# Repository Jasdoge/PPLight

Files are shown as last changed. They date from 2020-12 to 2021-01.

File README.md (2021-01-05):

# Usage:

1. The lamp automatically turns on when you move it
2. The lamp starts fading out after being still for 30 seconds, fully turning off after another 30 seconds.

## Charging:

1. Plug it to a 5V USB outlet with a Type-C cable.
2. The battery only charges at 100mA, so even a computer port will be able to charge it.
3. While charging, the lights will fade in and out with a pause between.
4. When fully charged, the lights will turn off.
5. A fully discharged battery reaches 90%+ charge in 2 hours.

## Troubleshooting:

1. After charging, you may need to led the device be still for a few seconds before it can turn on again.
2. If the device still won't turn on, you may need to reset it (this should be exceedingly rare though, and I didn't manage to reproduce it myself after setting the proper BOD). To reset it, open the case by removing the lid (but be careful since the silk filament is a little brittle), and use a fork or knife to briefly short the BAT1 solder joints.

# 3d printing

The 3d print files are located in the Prints director. It's designed for a multi material printer where you want to combine the lid and logo into one mesh, giving the logo priority.

# Schematics

Schematics are located within the Kicad directory.

# Reprogramming

If you want to reprogram your light you'll need the following:

- An arduino (pref arduino UNO)
- A breadboard
- A 10uF electrolytic capacitor
- A 4.7 kOhm resistor.
- 8-pin SOIC test clips. https://www.aliexpress.com/item/33058340727.html

1. Install the MegaTinyCore library in arduino. (If you haven't installed Arduino, do so at https://www.arduino.cc/
2. Then follow the instructions here: https://github.com/SpenceKonde/megaTinyCore/blob/master/MakeUPDIProgrammer.md But **do not connect the power pin to the PPLight**. In the tutorial they use a 470 ohm resistor on the UPDI wire, you can use a 4.7k instead, it doesn't matter that much.
3. Connect pin 6 of your arduino to your breadboard, then to pin 6 of the clips (second from the bottom right, the red wire on the clips is top left).
4. Connect ground to the top right of your test clips.
5. Connect the clips to the attiny on the board. The chamfered edge is left. Align it so the red cable on the clips is top left.
6. Use the following arduino settings:
- Board: ATtiny412/402/212/202
- Chip: ATtiny402
- Clock: 1 MHz internal
- millis()/micros(): Enabled (default timer)
- Support SerialEvent: No
- Port: Port of your arduino
- Programmer: jtag2updi
- The rest don't matter. Don't burn bootloader unless you know what you're doing.
7. You should now be able to upload your code.

**Note: If you're struggling with these instructions, let me know and I'll make a youtube video**

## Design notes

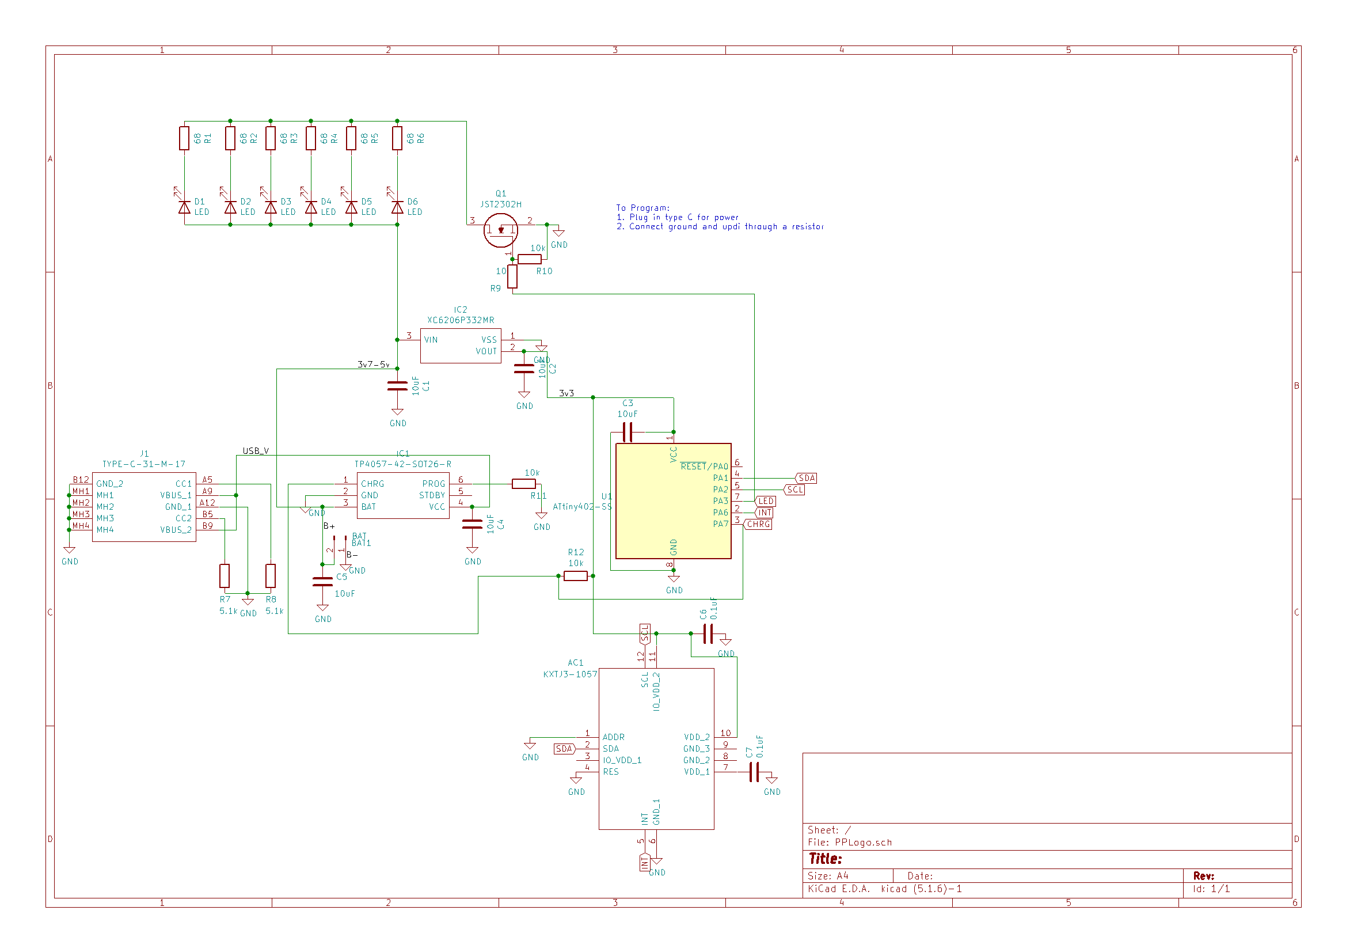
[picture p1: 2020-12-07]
Kicad/pplight_schematic.png

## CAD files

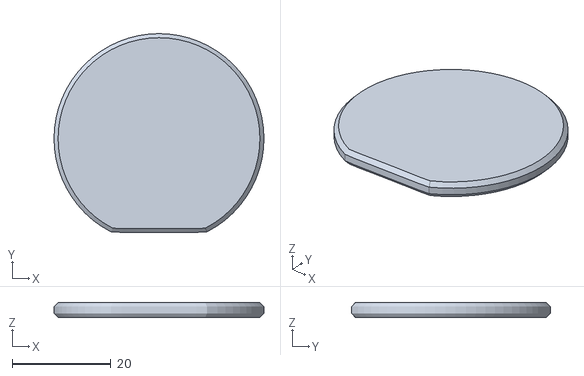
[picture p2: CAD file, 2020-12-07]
Prints/pplight_lid.STL
42.6 x 40.3 x 3.08

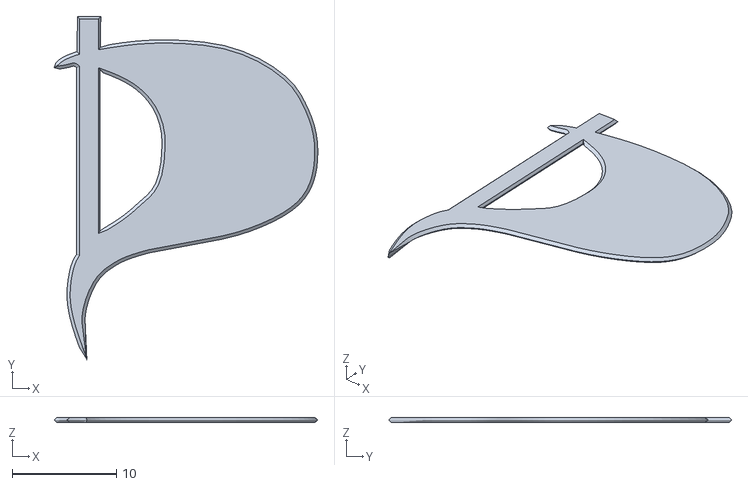
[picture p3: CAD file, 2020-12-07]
Prints/pplight_logo.STL
25.2 x 32.8 x 0.513

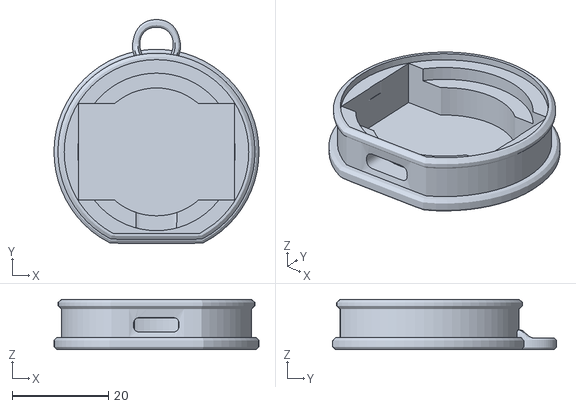
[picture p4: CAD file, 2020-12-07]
Prints/pplight_base.STL
42.6 x 46.5 x 10.4

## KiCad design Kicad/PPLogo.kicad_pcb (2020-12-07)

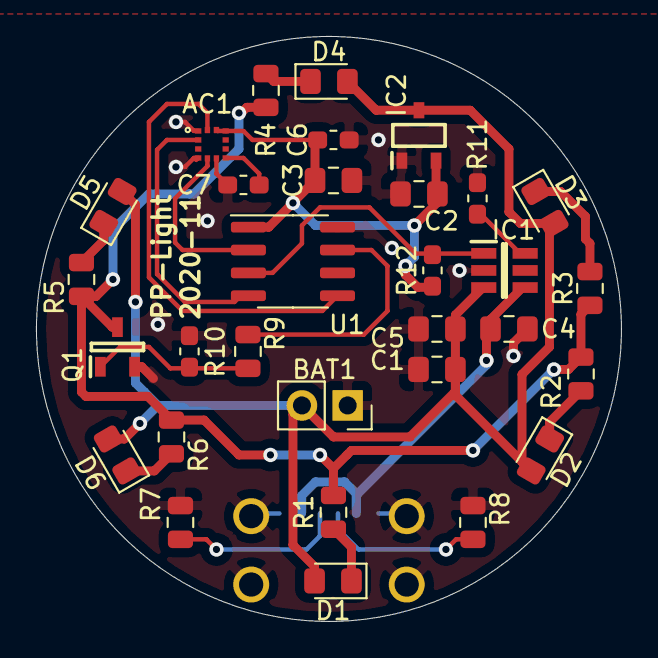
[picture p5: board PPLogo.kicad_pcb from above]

Board: 2 copper layers, 32.5 x 32.5 mm, 32 parts (1 on the bottom side), 21 nets.

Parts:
AC1: KXTJ3-1057; 2X2X0.9MMLGA
BAT1: BAT; PinSocket_1x02_P2.54mm_Vertical
C1, C2, C3, C4, C5: 10uF; C_0805_2012Metric_Pad1.15x1.40mm_HandSolder
C6, C7: 0.1uF; C_0603_1608Metric_Pad1.05x0.95mm_HandSolder
D1, D2, D3, D4, D5, D6: LED; LED_0805_2012Metric_Pad1.15x1.40mm_HandSolder
IC1: TP4057-42-SOT26-R; SOT95P280X125-6N
IC2: XC6206P332MR; SOT95P280X130-3N
J1: TYPE-C-31-M-17; TYPEC31M17
Q1: JST2302H; SOT95P240X115-3N
R1, R2, R3, R4, R5, R6: 220; R_0805_2012Metric
R7, R8: 5.1k; R_0805_2012Metric
R9: 10; R_0805_2012Metric
R10, R11, R12: 10k; R_0603_1608Metric_Pad1.05x0.95mm_HandSolder
U1: ATtiny402-SS; SOIC-8_3.9x4.9mm_P1.27mm

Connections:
/3v3: AC1.10, AC1.11, C2.2, C3.1, C6.1, IC2.2, R12.1, U1.1
/3v7-5v: BAT1.2, C1.2, C5.1, D1.2, D2.2, D3.2, D4.2, D5.2, D6.2, IC1.3, IC2.3
/USB_V: C4.2, IC1.4, J1.A9, J1.B9
CHRG: IC1.1, R12.2, U1.3
GND: AC1.1, AC1.4, AC1.6, BAT1.1, C1.1, C2.1, C3.2, C4.1, C5.2, C6.2, C7.2, IC1.2, IC2.1, J1.A12, J1.B12, J1.MH1, J1.MH2, J1.MH3, J1.MH4, Q1.2, R7.2, R8.2, R10.1, R11.1, U1.8
INT: AC1.5, U1.2
LED: R9.2, U1.7
unnamed: AC1.7, C7.1
unnamed: D1.1, R1.1
unnamed: D2.1, R2.1
unnamed: D3.1, R3.1
unnamed: D4.1, R4.1
unnamed: D5.1, R5.1
unnamed: D6.1, R6.1
unnamed: IC1.6, R11.2
unnamed: J1.A5, R8.1
unnamed: J1.B5, R7.1
unnamed: Q1.1, R9.1, R10.2
unnamed: Q1.3, R1.2, R2.2, R3.2, R4.2, R5.2, R6.2
SCL: AC1.12, U1.5
SDA: AC1.2, U1.4

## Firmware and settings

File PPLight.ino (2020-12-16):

#include "_Config.h"
#include <avr/sleep.h>
#define overrideError
#include "Shibetek-KXTJ3.h"

// Variables
uint32_t wake = 0;				// Keepalive timer
uint32_t last_frame = 0;		// Last frame time (used for the animation ticker)
bool charging = false;
bool wokeByTimer = false;		// Tracks if it woke by timer. Used for reading battery charge status
uint32_t last_charge_check = 0;	// Limits how often to read the battery
bool sleepOnLoop = false;		// Used to prevent recursion

// Woke due to pin interrupt
ISR(PORTA_PORT_vect){
	uint8_t flags=PORTA.INTFLAGS;
  	PORTA.INTFLAGS=flags; //clear flags
}

ISR(RTC_PIT_vect){
  	RTC.PITINTFLAGS = RTC_PI_bm;          /* Clear interrupt flag by writing '1' (required) */
	wokeByTimer = true;
}

// Support functions
void setLEDs( uint16_t pwm = 0 ){
	analogWrite(PIN_LED, pwm);
};



// Turns the lights on or off
void toggle( bool on = false ){

	// Off
	if( !on ){

		wake = 0;
		setLEDs();
		sleep();
		return;

	}

	// On
	wake = millis();
	

}



void sleep(){
	
	PORTA.PIN6CTRL = 0b00000001;	// Trigger high
	sleep_cpu();

	// Just on to check if we're charging
	if( wokeByTimer ){
		
		wokeByTimer = false;
		checkCharging(true);
		
		// not plugged in, go back to sleep immediately
		if( !charging ){
			sleepOnLoop = true;
			return;
		}

	}

	// We're either charging or woke by a shake. In either case handle the sensor, otherwise it gets borked when you unplug the charger

	// woek up
	PORTA.PIN7CTRL = 0b00000000;	// Disable pin interrupt

	
	toggle(true);	// Woke, turn on

}

void checkCharging( bool force ){

	#ifdef DEBUG_IGNORE_BATTERY

	charging = false;

	#else

	const uint32_t ms = millis();
	if( !force && ms-last_charge_check < 1000 )
		return;
	
	last_charge_check = ms;

	const bool pre = charging;
	charging = !digitalRead(PIN_CHARGE_DET);

	// Turn on after charging finishes
	if( !charging && pre )
		toggle(true);
	
	

	#endif

}




void setup(){


	/* Initialize RTC: */
	while (RTC.STATUS > 0){
		;                                   /* Wait for all register to be synchronized */
	}
	RTC.CLKSEL = RTC_CLKSEL_INT32K_gc;    /* 32.768kHz Internal Ultra-Low-Power Oscillator (OSCULP32K) */
	RTC.PITINTCTRL = RTC_PI_bm;           /* PIT Interrupt: enabled */
	RTC.PITCTRLA = RTC_PERIOD_CYC32768_gc /* RTC Clock Cycles 32k, 1Hz ( */
	| RTC_PITEN_bm;                       /* Enable PIT counter: enabled */

	set_sleep_mode(SLEEP_MODE_PWR_DOWN);
	sleep_enable();
	
	// The permanent output pins can be set here
	pinMode(PIN_LED, OUTPUT);
	digitalWrite(PIN_LED, HIGH);
	delay(100);
	digitalWrite(PIN_LED, LOW);

	// Interrupt ALWAYS needs to be an input
	pinMode(PIN_INTERRUPT, INPUT);
	pinMode(PIN_CHARGE_DET, INPUT_PULLUP);

	setLEDs(5);
	
	if( !Accelerometer::begin() ){

		for( uint8_t i = 0; i<10; ++i ){

			setLEDs(i%2 ? 5 : 100);
			delay(500);

		}
		digitalWrite(PIN_LED, LOW);
		while(true);

	}

	setLEDs(50);
	delay(100);
	setLEDs(0);

	// sensitivity, duration to trigger, duration to reset
	if( !Accelerometer::setInterrupt( 40, 10, 255 ) ){
		for( uint8_t i = 0; i<20; ++i ){
			setLEDs(i%2 ? 5 : 20);
			delay(100);
		}
		return;
	}

	for( uint8_t i =0; i < 5; ++i ){
		setLEDs(i*50);
		delay(200);
	}
	
	
	toggle(digitalRead(PIN_INTERRUPT));



}

void loop(){


	// This is a recursion breaker
	if( sleepOnLoop ){

		sleepOnLoop = false;
		toggle(false);
		return;

	}



	checkCharging(false);
	
	
	const uint32_t ms = millis();


	// While charging. Only animate charge, regular functionality is disabled
	if( charging ){
		
		const uint16_t ANIM_TIME = 5000;
		const uint16_t ANIM_MAX_BRIGHT = 50;
		const uint16_t ANIM_MIN_BRIGHT = 1;

		uint16_t curTime = ms%(ANIM_TIME*2);
		uint16_t brightness = 0;
		if( curTime <= ANIM_TIME ){

			bool down = curTime > ANIM_TIME/2;
			// Need to animate in and out
			if( down ){
				// Animate down
				curTime = curTime-ANIM_TIME/2;
			}
			
			brightness = map(curTime, 0, ANIM_TIME/2, ANIM_MIN_BRIGHT, ANIM_MAX_BRIGHT);
			if( down )
				brightness = ANIM_MAX_BRIGHT-brightness;

		}

		setLEDs(brightness);

		return;

	}

	// Not charging, do normal stuff
	
	// Animate
	if( ms-last_frame > 10 ){

		last_frame = ms;

		uint16_t brightness = ms%500;	// 2 blinks per second
		if( brightness >= 250 )
			brightness = 250-(brightness-250);

		brightness = map(brightness, 0, 250, 0, MAX_BRIGHTNESS);

		// Time to fade
		if( ms-wake > KEEPALIVE_DURATION ){

			uint16_t fade = ms-wake-KEEPALIVE_DURATION;	// how far between 0 and FADE_TIME are we in MS?
			fade = map(fade, 0, FADE_TIME, 0, MAX_BRIGHTNESS);
			if( fade > brightness )
				brightness = 0;
			else
				brightness -= fade;

		}

		setLEDs(brightness);


	}

	// We're still alive
	if( ms-wake < ON_DUR ){

		if( digitalRead(PIN_INTERRUPT) )
			wake = ms;
		
	}
	// Timer has expired, shut down
	else
		toggle();



}

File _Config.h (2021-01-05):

#ifndef __neoPocketConf
#define __neoPocketConf

const uint32_t KEEPALIVE_DURATION = 10000; //150000;	// Use ON_DUR
const uint32_t FADE_TIME = 10000;			// This is appended to KEEPALIVE_DURATION
#define ON_DUR (KEEPALIVE_DURATION+FADE_TIME)

const uint16_t MAX_BRIGHTNESS = 150;

#define PIN_INTERRUPT 0			// Turns on on LOW
#define PIN_CHARGE_DET 1
#define PIN_LED 4

#endif

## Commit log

2020-12-07 Add assets
    [PPLogo.kicad_pcb, PPLogo.sch, pplight_base.STL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]
2020-12-07 add schematic png
2021-01-05 Lowered brightness and duration to save battery
